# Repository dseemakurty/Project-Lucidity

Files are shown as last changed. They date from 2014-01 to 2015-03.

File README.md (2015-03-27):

Welcome to Project Lucidity

At its core, Project Lucidity is a sleep mask that helps you attain the elusive lucid dream. But this project is more than that. Its about taking the art of controlling your dreams and bringing it from a shaky phenomenon to a more understood science. To do so, Project Lucidity was designed as a fully featured, hobbyist and developer friendly, lucid dreaming mask that goes above and beyond. 

For more information about the project, check out the main website at: http://dseemakurty.wix.com/project-lucidity

All the code, schematics, and eagle files have been uploaded into this github. Feel free to utilize this information for your personal designs but please check the license file for any concerns about the contents use.

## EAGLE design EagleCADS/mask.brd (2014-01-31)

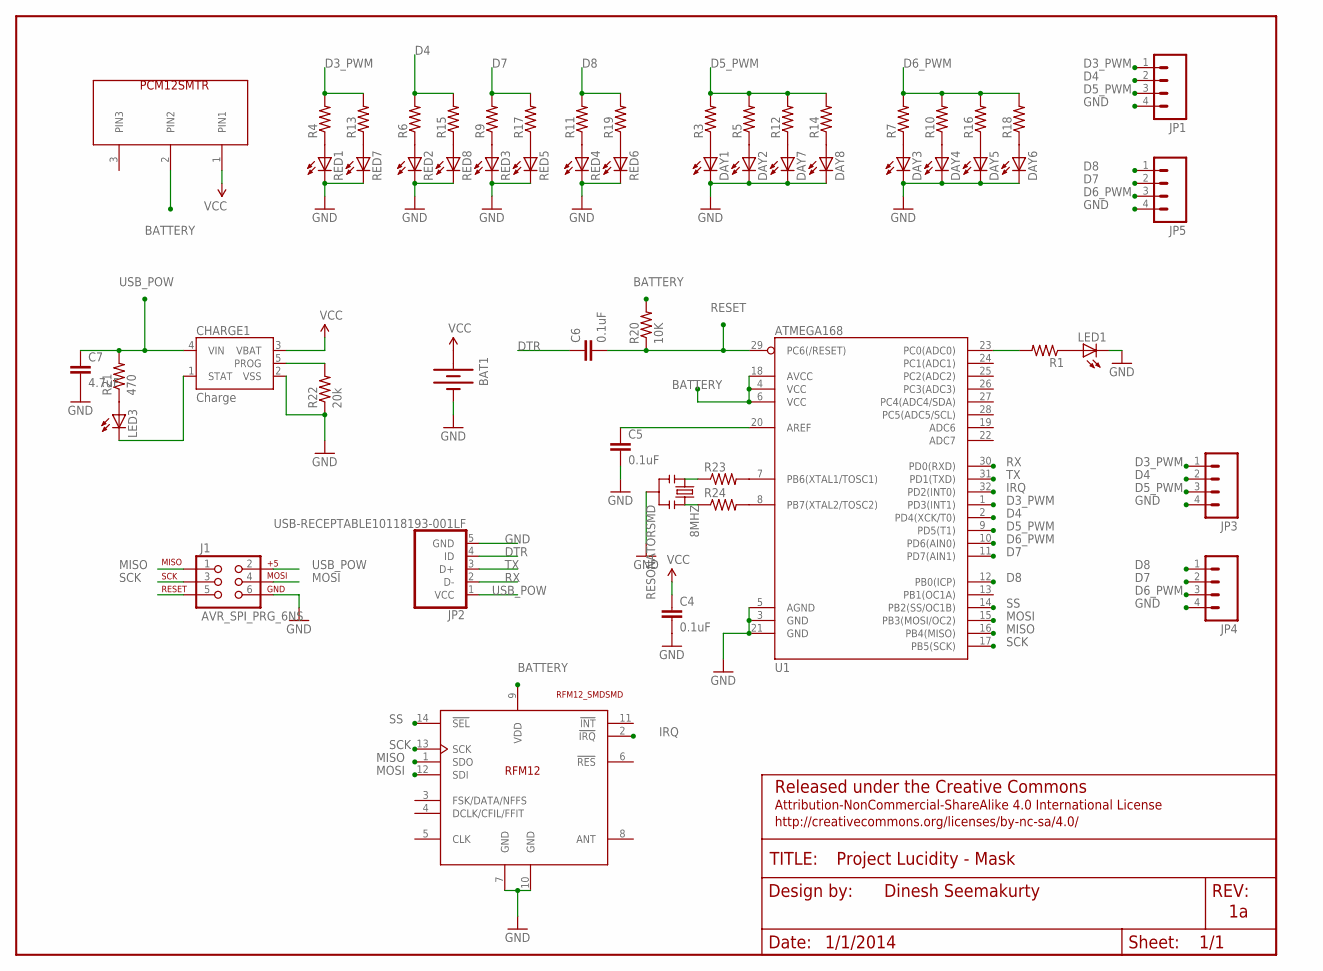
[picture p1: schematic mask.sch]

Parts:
8MHZ: RESONATORSMD; RESONATOR-SMD
BAT1: BATTERY245MM; BATTCON_245MM
C4, C5, C6: 0.1uF; 0805
C7: 4.7uF; 0805
CHARGE1: Charge; SOT23-5
DAY1, DAY2, DAY3, DAY4, DAY5, DAY6, DAY7, DAY8: LEDP-LCC-2; P-LCC-2
FRAME1: FRAME-LETTER; CREATIVE_COMMONS
J1: AVR_SPI_PRG_6NS; 2X3-NS
JP1, JP3, JP4, JP5: M04PTH; 1X04
JP2: USB-RECEPTABLE10118193-001LF; FCI-10118193-0001LF
LED1, LED3: LED0603; LED-0603
R1, R3, R4, R5, R6, R7, R9, R10, R11, R12, R13, R14, R15, R16, R17, R18, R19: RESISTOR0805-RES; 0805
R20: 10K; 0805
R21: 470; 0805
R22: 20k; 0805
R23, R24: RESISTOR0402-RES; 0402-RES
RED1, RED2, RED3, RED4, RED5, RED6, RED7, RED8: LEDCHIPLED_1206; CHIPLED_1206
U1: ATMEGA168; TQFP32-08
U$2: PCM12SMTR
U$3: RFM12_SMDSMD; RFM12

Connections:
BATTERY: R20.2, U1.4 (VCC), U1.6 (VCC), U1.18 (AVCC), U$2.2 (PIN2), U$3.9 (VDD)
D3_PWM: JP1.1, JP3.1, R4.2, R13.2, U1.1 (PD3(INT1))
D4: JP1.2, JP3.2, R6.2, R15.2, U1.2 (PD4(XCK/T0))
D5_PWM: JP1.3, JP3.3, R3.2, R5.2, R12.2, R14.2, U1.9 (PD5(T1))
D6_PWM: JP4.3, JP5.3, R7.2, R10.2, R16.2, R18.2, U1.10 (PD6(AIN0))
D7: JP4.2, JP5.2, R9.2, R17.2, U1.11 (PD7(AIN1))
D8: JP4.1, JP5.1, R11.2, R19.2, U1.12 (PB0(ICP))
DTR: C6.1, JP2.4 (ID)
GND: 8MHZ.2, BAT1.2 (-), C4.2, C5.2, C7.2, CHARGE1.2 (VSS), DAY1.P$2 (C), DAY2.P$2 (C), DAY3.P$2 (C), DAY4.P$2 (C), DAY5.P$2 (C), DAY6.P$2 (C), DAY7.P$2 (C), DAY8.P$2 (C), J1.6, JP1.4, JP2.5 (GND), JP3.4, JP4.4, JP5.4, LED1.C, R22.1, RED1.C, RED2.C, RED3.C, RED4.C, RED5.C, RED6.C, RED7.C, RED8.C, U1.3 (GND), U1.5 (AGND), U1.21 (GND), U$3.7 (GND), U$3.10 (GND)
IRQ: U1.32 (PD2(INT0)), U$3.2 (!IRQ)
MISO: J1.1, U1.16 (PB4(MISO)), U$3.1 (SDO)
MOSI: J1.4, U1.15 (PB3(MOSI/OC2)), U$3.12 (SDI)
unnamed: C5.1, U1.20 (AREF)
unnamed: LED1.A, R1.1
unnamed: R1.2, U1.23 (PC0(ADC0))
unnamed: DAY3.P$1 (A), R7.1
unnamed: DAY4.P$1 (A), R10.1
unnamed: DAY1.P$1 (A), R3.1
unnamed: R4.1, RED1.A
unnamed: R6.1, RED2.A
unnamed: DAY2.P$1 (A), R5.1
unnamed: LED3.A, R21.1
unnamed: R9.1, RED3.A
unnamed: R11.1, RED4.A
unnamed: CHARGE1.1 (STAT), LED3.C
unnamed: CHARGE1.5 (PROG), R22.2
unnamed: 8MHZ.1, R23.1
unnamed: 8MHZ.3, R24.1
unnamed: R13.1, RED7.A
unnamed: R15.1, RED8.A
unnamed: R23.2, U1.7 (PB6(XTAL1/TOSC1))
unnamed: R17.1, RED5.A
unnamed: R19.1, RED6.A
unnamed: DAY5.P$1 (A), R16.1
unnamed: DAY6.P$1 (A), R18.1
unnamed: DAY7.P$1 (A), R12.1
unnamed: DAY8.P$1 (A), R14.1
unnamed: R24.2, U1.8 (PB7(XTAL2/TOSC2))
RESET: C6.2, J1.5, R20.1, U1.29 (PC6(/RESET))
RX: JP2.2 (D-), U1.30 (PD0(RXD))
SCK: J1.3, U1.17 (PB5(SCK)), U$3.13 (SCK)
SS: U1.14 (PB2(SS/OC1B)), U$3.14 (!SEL)
TX: JP2.3 (D+), U1.31 (PD1(TXD))
USB_POW: C7.1, CHARGE1.4 (VIN), J1.2, JP2.1 (VCC), R21.2
VCC: BAT1.1 (+), C4.1, CHARGE1.3 (VBAT), U$2.1 (PIN1)

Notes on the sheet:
Released under the Creative Commons
Attribution-NonCommercial-ShareAlike 4.0 International License
http://creativecommons.org/licenses/by-nc-sa/4.0/
Project Lucidity - Mask
Dinesh Seemakurty
1/1/2014

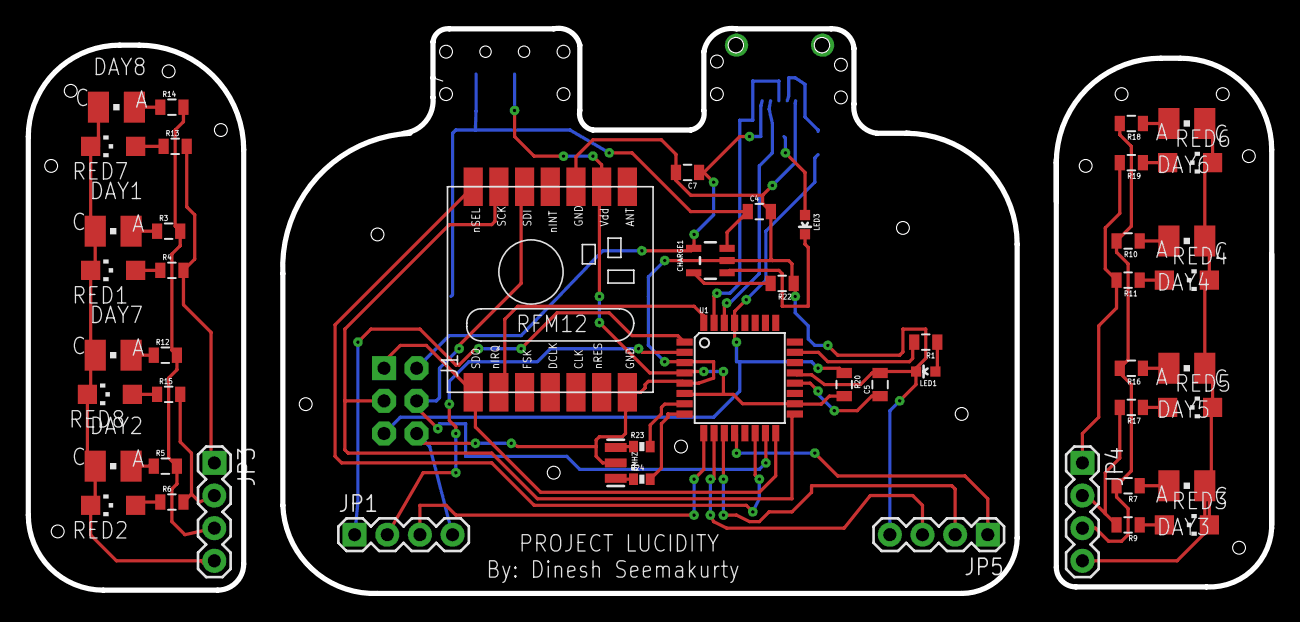
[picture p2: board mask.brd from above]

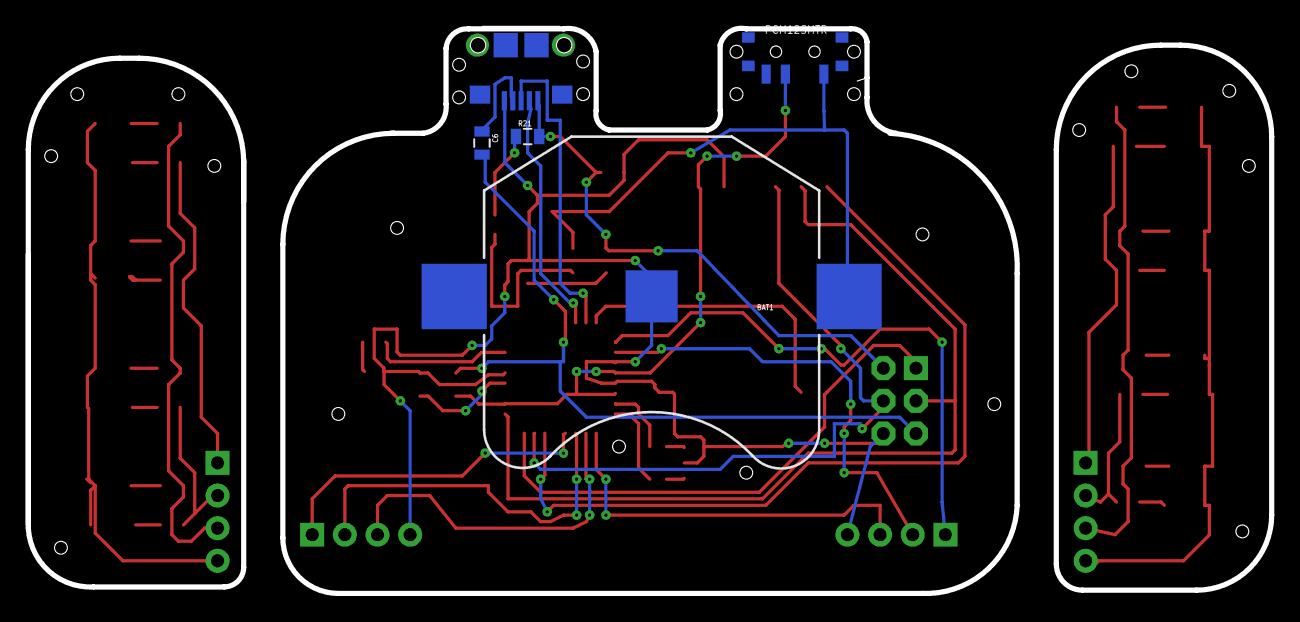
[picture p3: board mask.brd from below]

Board: 2 copper layers, 96.8 x 44.0 mm, 57 parts (5 on the bottom side), 45 nets.

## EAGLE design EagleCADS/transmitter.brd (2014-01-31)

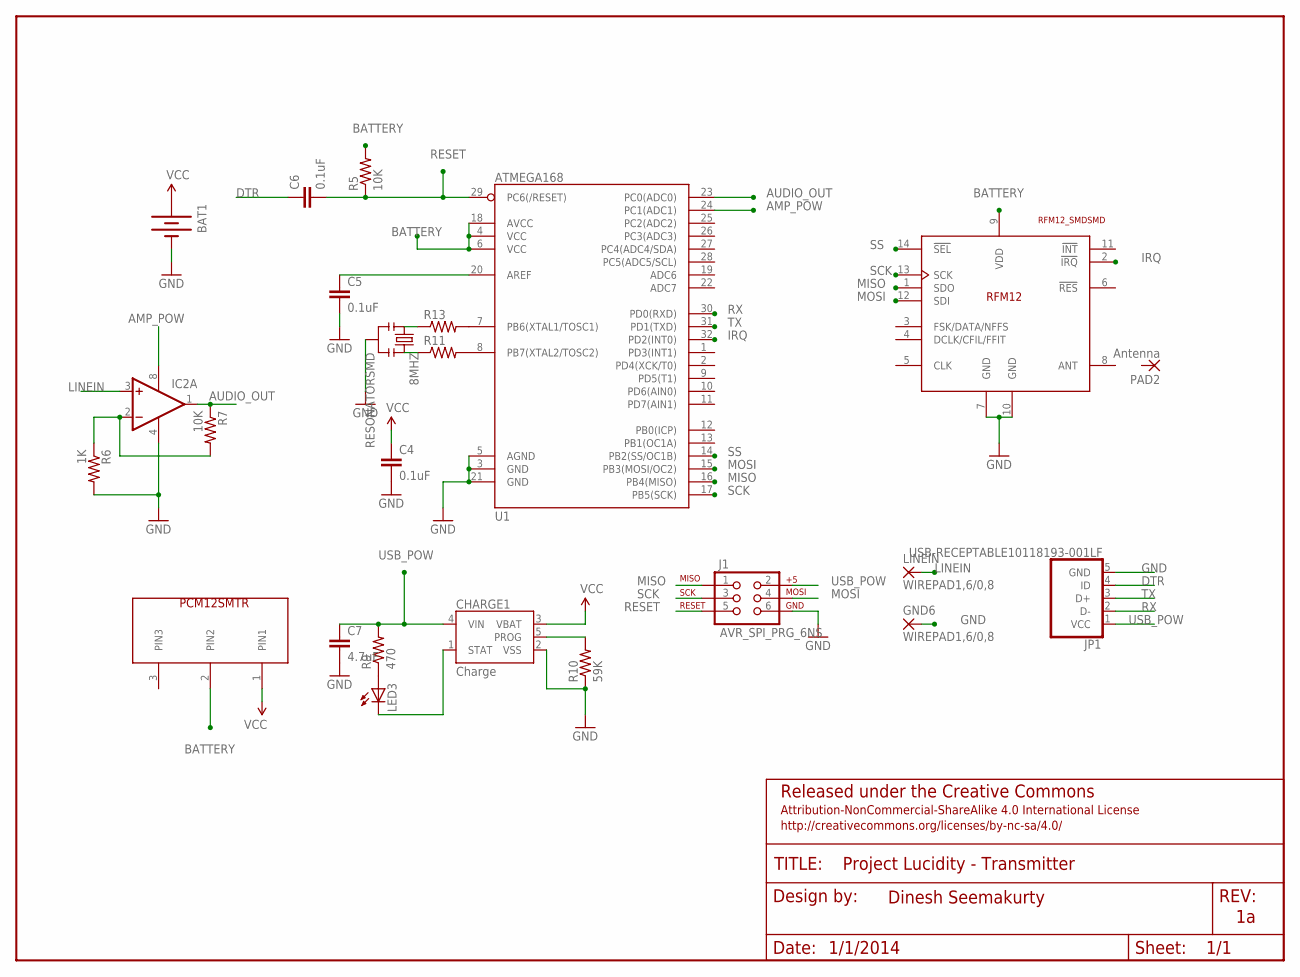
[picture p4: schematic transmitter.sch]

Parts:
8MHZ: RESONATORSMD; RESONATOR-SMD
BAT1: BATTERY20MM_4LEGS; BATTCON_20MM_4LEGS
C4, C5, C6: 0.1uF; 0805
C7: 4.7uF; 0805
CHARGE1: Charge; SOT23-5
FRAME1: FRAME-LETTER; CREATIVE_COMMONS
GND6: WIREPAD1,6/0,8; 1,6/0,8
IC2: LM358D; SO08
J1: AVR_SPI_PRG_6NS; 2X3-NS
JP1: USB-RECEPTABLE10118193-001LF; FCI-10118193-0001LF
LED3: LED0603; LED-0603
LINEIN: WIREPAD1,6/0,8; 1,6/0,8
PAD2: Antenna; SMD1,27-2,54
R5, R7: 10K; 0805
R6: 1K; 0805
R9: 470; 0805
R10: 59K; 0805
R11, R13: RESISTOR0402-RES; 0402-RES
U1: ATMEGA168; TQFP32-08
U$2: PCM12SMTR
U$3: RFM12_SMDSMD; RFM12

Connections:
AMP_POW: IC2.8 (V+), U1.24 (PC1(ADC1))
AUDIO_OUT: IC2.1 (OUT), R7.1, U1.23 (PC0(ADC0))
BATTERY: R5.2, U1.4 (VCC), U1.6 (VCC), U1.18 (AVCC), U$2.2 (PIN2), U$3.9 (VDD)
DTR: C6.1, JP1.4 (ID)
GND: 8MHZ.2, BAT1.GND (-), C4.2, C5.2, C7.2, CHARGE1.2 (VSS), GND6.1, IC2.4 (V-), J1.6, JP1.5 (GND), R6.2, R10.1, U1.3 (GND), U1.5 (AGND), U1.21 (GND), U$3.7 (GND), U$3.10 (GND)
IRQ: U1.32 (PD2(INT0)), U$3.2 (!IRQ)
LINEIN: IC2.3 (+IN), LINEIN.1
MISO: J1.1, U1.16 (PB4(MISO)), U$3.1 (SDO)
MOSI: J1.4, U1.15 (PB3(MOSI/OC2)), U$3.12 (SDI)
unnamed: R13.2, U1.7 (PB6(XTAL1/TOSC1))
unnamed: C5.1, U1.20 (AREF)
unnamed: R11.2, U1.8 (PB7(XTAL2/TOSC2))
unnamed: LED3.A, R9.1
unnamed: IC2.2 (-IN), R6.1, R7.2
unnamed: CHARGE1.1 (STAT), LED3.C
unnamed: CHARGE1.5 (PROG), R10.2
unnamed: 8MHZ.1, R13.1
unnamed: 8MHZ.3, R11.1
RESET: C6.2, J1.5, R5.1, U1.29 (PC6(/RESET))
RX: JP1.2 (D-), U1.30 (PD0(RXD))
SCK: J1.3, U1.17 (PB5(SCK)), U$3.13 (SCK)
SS: U1.14 (PB2(SS/OC1B)), U$3.14 (!SEL)
TX: JP1.3 (D+), U1.31 (PD1(TXD))
USB_POW: C7.1, CHARGE1.4 (VIN), J1.2, JP1.1 (VCC), R9.2
VCC: BAT1.POW1 (+), BAT1.POW2 (+), BAT1.POW3 (+), BAT1.POW4 (+), C4.1, CHARGE1.3 (VBAT), U$2.1 (PIN1)

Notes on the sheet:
Released under the Creative Commons
Attribution-NonCommercial-ShareAlike 4.0 International License
http://creativecommons.org/licenses/by-nc-sa/4.0/
Project Lucidity - Transmitter
Dinesh Seemakurty
1/1/2014

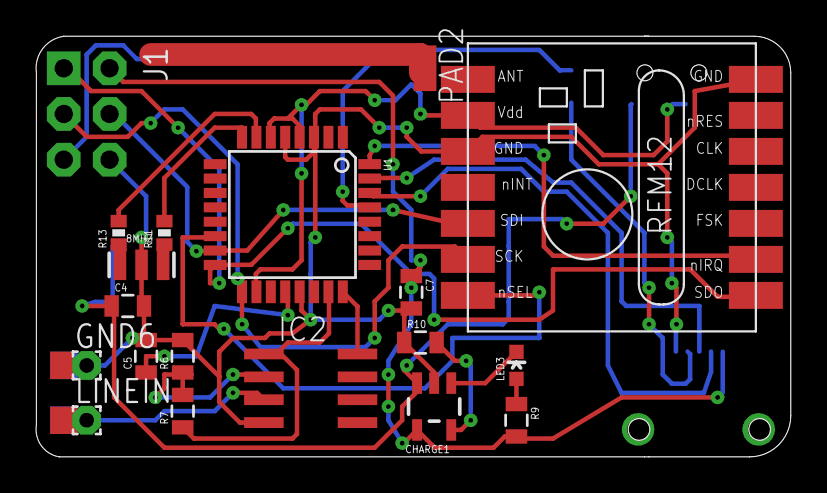
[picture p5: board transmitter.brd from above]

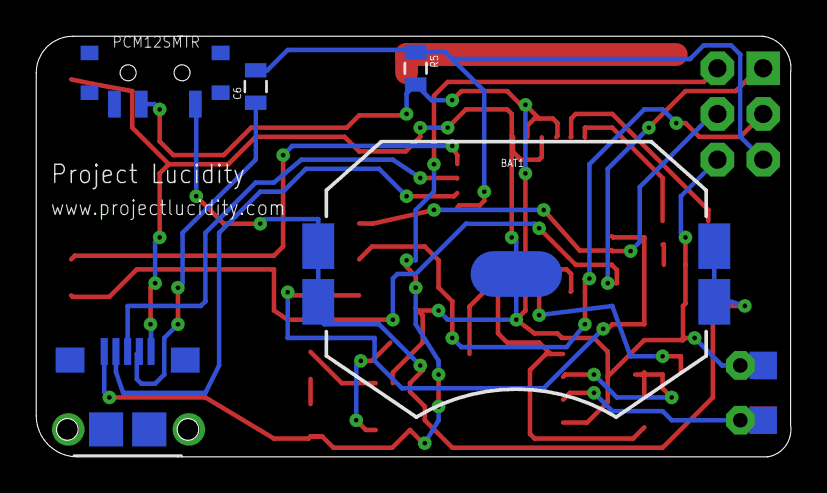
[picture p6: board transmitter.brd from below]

Board: 2 copper layers, 41.9 x 23.4 mm, 25 parts (5 on the bottom side), 25 nets.

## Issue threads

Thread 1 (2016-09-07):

BOM needed

autrion, 2016-09-07:
Hi, thanks for this great work! In my opinion the best mask out there as you could also use it e.g. as "alarm" which is not supported by other devices.

One thing: I could use a BoM (Bill of materials) in order to build it myselve. Is it possible to etch the board by oneselve?

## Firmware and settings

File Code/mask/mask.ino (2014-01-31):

#include <SoftPWM.h>
#include <SPI.h>
#include <avr/interrupt.h>
#include <avr/power.h>
#include <avr/sleep.h>
#include <avr/io.h>
#include <avr/wdt.h>
#include <RFM12B.h>

//**********************************************************************************//

#define numRedLeds 4
#define ledPin1 3
#define ledPin2 4
#define ledPin3 7
#define ledPin4 8
#define statusLED A0
int LEDS[numRedLeds] = {
  ledPin1,ledPin2,ledPin3,ledPin4};
int startOn[numRedLeds]; // the time in ISR time units when the LEDs should activate

#define daylightPin1 5
#define daylightPin2 6
#define daylightMaxBrightness 255 // the maximum brightness the LEDs can reach
#define daylightIncreaseInterval 1 // how much the PWM should increase per refresh (out of 255)
#define daylightInterval 2 // (255*(600ms/1000ms))/60s = 2.55 minutes
int daylightRefreshIntervalT; //interval between refreshes in terms of ISR time units, function of the daylightInterval and settings assigned by user
int daylightBrightness; //brightness of the daylight simulation as a function of received setting
int daylightFadeLevel = 0; // the fade level of the daylight LEDs

// @16Mhz overflow of 155 = 10ms :::: @8Mhz overflow of 78 = 10ms
#define timerOverflow 78 // this overflow amount on the 16bit Timer1 will create 10ms overflows
#define interruptInterval 10 //one ISR time unit is this many milliseconds based on clock calculations

//fade speeds for the different patterns
#define flashAllFadeTime 200
#define sweepFadeTime 200
#define alternatingFadeTime 200
#define doubleFlashFadeTime 50
int sweepDelay; //delay between LED's on the sweep pattern
double patternBrightness; // will be modified by received settings
double patternSpeed; // will be modified by received settings

int fadeTime; // how long the fading process should take in ms
int fadeT; // fadeTime in ISR time units
double redBrightnessPercent; // will be modified by various settings, the actual brightness of the red LEDs
double redFadeTime; //the time sent to the SoftPWM library incorporating brightness level and actual fadeTime
#define patternRefillTime 30000 // how long a pattern will project after receiving the signal
#define previewPatternRefillTime 3000
int patternDisplayTime; // how long a pattern should be displayed, must be refilled with time after use
int patternT = 0; // patternDisplayTime in ISR time units

volatile long redT = 0; // ticks every timer overflow
volatile long daylightT = 0; // ticks only when runDaylight boolean is enabled

boolean runDaylight = false; //triggers Daylight Simulation
boolean flashAllP = false; //triggers all LEDs to flash pattern
boolean sweepRightP = false; // triggers sweep pattern (ONLY ENABLE RIGHT OR LEFT TO START SWEEP)
boolean sweepLeftP = false; // triggers sweep pattern (ONLY ENABLE RIGHT OR LEFT TO START SWEEP)
boolean alternatingFlashP = false; // triggers flashing of each eye's LEDs alternatingly
boolean doubleFlashP = false; // double flash then delayLong
int longCount = -1;
int delayLong;
boolean *patternPointer; // boolean to point to one of the above booleans (used in updateReds() method)
int resetT = -1; // when the pattern is finished one cycle in ISR time units

#define NODEID 1
#define NETWORKID 99
unsigned int msg; // the message that will be received from the tranceiver
RFM12B radio;
boolean keepListening = true; // 
long startListeningTime;
#define listenTimeout 200 //how long to listen before timeing out

// Watchdog timeout values
// 0=16ms, 1=32ms, 2=64ms, 3=128ms, 4=250ms, 5=500ms
// 6=1sec, 7=2sec, 8=4sec, 9=8sec
#define wdTime 9 // watchdog timeout value
#define tempwdTime 6
#define wdMultiple 3 // how many times to execute wdTime (gets larger sleep times)
#define tempwdMultiple 1 // how many times to execute wdTime (gets larger sleep times)
#define idleTimeout 4320 //multiply by wdTime(ms value) and wdMultiple to get the time of the timeout, will put mask into deep sleep without WDT
#define tempIdleTimeout 60 // preview timeout allows for quick polling (set for 1 minute)
long idleTimer = 0; // counter that is compared to the sleepTimeout
volatile boolean f_wdt = 0; // WDT int
byte adcsra;

void setup()
{
  SoftPWMBegin();
  Serial.begin(115200);
  pinMode(statusLED,OUTPUT);
  setupTimerInterrupt();
  radio.Initialize(NODEID,RF12_433MHZ,NETWORKID);
  Serial.println("Listening..");
}

// sets up all the calculations around properly fading the LEDs
void setupSoftPWM(int fadetime, double brightness)
{
  fadeTime = fadetime;
  fadeT = fadeTime/interruptInterval;
  redBrightnessPercent = brightness;
  redFadeTime = fadeTime*(100/redBrightnessPercent); // recalculates the time for the SoftPWM library since library times things differently
  sweepDelay = fadeT/2;
  delayLong = fadeT*10;
  SoftPWMSet(ledPin1, 0);
  SoftPWMSetFadeTime(ledPin1, redFadeTime, redFadeTime);
  SoftPWMSet(ledPin2, 0);
  SoftPWMSetFadeTime(ledPin2, redFadeTime, redFadeTime);
  SoftPWMSet(ledPin3, 0);
  SoftPWMSetFadeTime(ledPin3, redFadeTime, redFadeTime);
  SoftPWMSet(ledPin4, 0);
  SoftPWMSetFadeTime(ledPin4, redFadeTime, redFadeTime);
}

// sets up timer 1 with 10ms overflow
void setupTimerInterrupt()
{
  cli();          // disable global interrupts
  TCCR1A = 0;     // set entire TCCR1A register to 0
  TCCR1B = 0;     // same for TCCR1B
  OCR1A = timerOverflow; // set to overflow ever 10ms
  TCCR1B |= (1 << WGM12); // turn on CTC mode:
  TCCR1B |= (1 << CS10);  // Set CS10 and CS12 bits for 1024 prescaler:
  TCCR1B |= (1 << CS12);
  TIMSK1 |= (1 << OCIE1A); // enable timer compare interrupt:
  sei();          // enable global interrupts
}

void analyzeMessage(unsigned int msg)
{

  double brightSetting = msg%10;  // the ones digit of the int received is the brightness setting
  msg = msg/10;                   // remove ones digit
  double speedSetting = msg%10;   // the previously tens digit is speed setting
  msg = msg/10;                   // remove ones digit
  int patternSetting = msg;       // the rest is the pattern indicator

  if (patternSetting == 1){
    daylightBrightness = daylightMaxBrightness * (brightSetting+1)/10;
    daylightRefreshIntervalT = daylightInterval * (speedSetting+1);
    runDaylight =true;
  }
  if (patternSetting == 2){
    patternBrightness = (brightSetting+1)*10;
    patternSpeed = flashAllFadeTime*10/(speedSetting+1);
    if (idleTimer<=tempIdleTimeout)
      setPattern(&flashAllP,previewPatternRefillTime,patternBrightness,patternSpeed);
    else setPattern(&flashAllP,patternRefillTime,patternBrightness,patternSpeed);
  }
  else if (patternSetting == 3){
    patternBrightness = (brightSetting+1)*10;
    patternSpeed = sweepFadeTime*10/(speedSetting+1);
    if (idleTimer<=tempIdleTimeout)
      setPattern(&sweepRightP,previewPatternRefillTime,patternBrightness,patternSpeed);
    else setPattern(&sweepRightP,patternRefillTime,patternBrightness,patternSpeed);
  }
  else if (patternSetting == 4){
    patternBrightness = (brightSetting+1)*10;
    patternSpeed = alternatingFadeTime*10/(speedSetting+1);
    if (idleTimer<=tempIdleTimeout)
      setPattern(&alternatingFlashP,previewPatternRefillTime,patternBrightness,patternSpeed);
    else setPattern(&alternatingFlashP,patternRefillTime,patternBrightness,patternSpeed);
  }
  else if (patternSetting == 5){
    patternBrightness = (brightSetting+1)*10;
    patternSpeed = doubleFlashFadeTime*10/(speedSetting+1);
    if (idleTimer<=tempIdleTimeout)
      setPattern(&doubleFlashP,previewPatternRefillTime,patternBrightness,patternSpeed);
    else setPattern(&doubleFlashP,patternRefillTime,patternBrightness,patternSpeed);
  }
}

void listenMessage()
{
  startListeningTime = millis();
  keepListening = true;
  while(millis()-startListeningTime<200 && keepListening) // listen for data for set time
  {
    if (radio.ReceiveComplete())
    {
      keepListening = false;
      if (radio.CRCPass())
      {
        char buffer[16]; // create character array
        for (byte i = 0; i < radio.GetDataLen(); i++)
          buffer[i] = (char)radio.Data[i];  // populate character array with data array
        int msg = atoi(buffer); // convert char array into an integer
        Serial.println(msg);
        radio.SendACK(); // send acknowledgement packet
        analyzeMessage(msg);
      }
    }
  }
}

void setPattern(boolean *patternpointer, int time, int brightness, int fadeSpeed)
{
  patternDisplayTime = time; // sets how long the pattern will be shown
  patternT = patternDisplayTime/interruptInterval; // recalculates time in ISR time units
  setupSoftPWM(fadeSpeed,brightness); // adjusts the SoftPWM settings
  *patternpointer = true; // activates the boolean that is sent to the method
}

void updateDaylight()
{
  if (daylightFadeLevel<=daylightBrightness){
    daylightFadeLevel+=daylightIncreaseInterval; // increase the PWM of the daylight LEDs
    analogWrite(daylightPin1, daylightFadeLevel);
    analogWrite(daylightPin2, daylightFadeLevel);
  }
  else{
    analogWrite(daylightPin1, 0); // turn off daylight LEDs
    analogWrite(daylightPin2, 0);
    daylightFadeLevel = 0;
    runDaylight = false; // technically unnecessary
    powerDown(); // after a daylight simulation, put the mask into deep sleep without WDT, requires manual reset
  }
}

void updateReds()
{
  for(int i = 0; i < numRedLeds;i++){
    if (redT == startOn[i]){ // iterates through all the LEDs and updates them based on the ISR time units
      SoftPWMSetPercent(LEDS[i],redBrightnessPercent);
    }
    else if (redT == startOn[i]+fadeT){ // turn off LEDs if they have reached peak brightness
      SoftPWMSetPercent(LEDS[i],0);
    }
  }
  if (redT==resetT){
    *patternPointer = true; // the value of the boolean that patternBoolean is addressed to is equal to True
    patternT-=resetT; // subracts the time for pattern to complete one cycle from the allotted display time
  }
}

void loop()
{

  if (f_wdt == 1){
    f_wdt=0;
    wdt_disable();
    
    radio.Wakeup();
    listenMessage();
    radio.Sleep();
  }
  else if (patternT<=0 && runDaylight == false){ // if freshly booted, poll at faster rate
    if (idleTimer<=tempIdleTimeout){
      setup_watchdog(tempwdTime);
      idleTimer++;
      timedSleep(tempwdMultiple);
    }
    else if (idleTimer<=idleTimeout){ //if activity timeout hasnt occured, enable watchdog and sleep
      setup_watchdog(wdTime);
      idleTimer++; // iterate idle timer
      timedSleep(wdMultiple); // put MCU to sleep
    }
    else{ // if timeout has occured, go into sleep without interrupts. can only be woken by reset button
      powerDown();
    }
  }

  // check all the pattern booleans to display pattern if one is valid
  if (flashAllP){
    redT=0;
    startOn[0] = redT+10;
    startOn[1] = redT+10;
    startOn[2] = redT+10;
    startOn[3] = redT+10;
    resetT = redT+10+fadeT*2; // the last possible redT that this pattern requires
    patternPointer = &flashAllP; //patternBoolean is the address of flashAll
    flashAllP = false;
    redT=0;
  }

  else if (sweepRightP){
    redT=0;
    startOn[0] = redT;
    startOn[1] = redT+sweepDelay;
    startOn[2] = redT+sweepDelay*2;
    startOn[3] = redT+sweepDelay*3;
    resetT = redT+sweepDelay*3+fadeT*2; // the last possible redT that this pattern requires for one cycle
    patternPointer = &sweepLeftP; //patternBoolean is the address of left sweep so sweep continues
    sweepRightP = false;
    redT=0;
  }

  else if (sweepLeftP){
    redT=0;
    startOn[3] = redT;
    startOn[2] = redT+sweepDelay;
    startOn[1] = redT+sweepDelay*2;
    startOn[0] = redT+sweepDelay*3;
    resetT = redT+sweepDelay*3+fadeT*2; // the last possible redT that this pattern requires for one cycle
    patternPointer = &sweepRightP; //patternBoolean is the address of right sweep so sweep continues
    sweepLeftP = false;
    redT=0;
  }

  else if (alternatingFlashP){
    redT=0;
    startOn[0] = redT;
    startOn[1] = redT;
    startOn[2] = redT+fadeT*2;
    startOn[3] = redT+fadeT*2;
    resetT = redT+fadeT*4; // the last possible redT that this pattern requires for one cycle
    patternPointer = &alternatingFlashP; //patternBoolean is the address of alternating flash
    alternatingFlashP = false;
    redT=0;
  }

  else if (doubleFlashP){
    if (longCount == 1){ // after two blinks, take long pause
      longCount = 0;
      redT=0;
      startOn[0] = redT+delayLong+10; // delayLong is a multiple of the fade
      startOn[1] = redT+delayLong+10;
      startOn[2] = redT+delayLong+10;
      startOn[3] = redT+delayLong+10;
      resetT = redT+delayLong+fadeT*4; // the last possible redT that this pattern requires for one cycle
    }
    else { 
      longCount++;
      redT=0;
      startOn[0] = redT+10;
      startOn[1] = redT+10;
      startOn[2] = redT+10;
      startOn[3] = redT+10;
      resetT = redT+fadeT*4; // the last possible redT that this pattern requires for one cycle
    }
    patternPointer = &doubleFlashP; //patternBoolean is the address of double flash
    doubleFlashP = false;
    redT=0;
  }
}

// Main timer that allows for smooth updating of patterns, interrupts ever 10ms
ISR(TIMER1_COMPA_vect)
{
  if (runDaylight){
    daylightT++;
    if (daylightT >= daylightRefreshIntervalT)
    {
      updateDaylight();
      daylightT = 0;
    }
  }
  if (patternT>0){
    updateReds();
    redT++;
  }
}


//*********************************************************************************************//
//*********************************************************************************************//

// allows for longer sleep times which are multiples of wdTime
void timedSleep(int waitTime)
{
  int waitCounter = 0;
  while (waitCounter != waitTime) 
  {
    enterSleep();
    waitCounter++;
  }
}

// puts the mC to power down sleep and has no interrupt or watchdog, can only be awoken by reset
void powerDown()
{
  digitalWrite(statusLED,LOW);
  enterSleep();
}


//*********************************************************************************************//
//*********************************************************************************************//

//sets up the watchdog to the correct sleep time
void setup_watchdog(int ii) 
{  
  // The prescale value is held in bits 5,2,1,0
  // This block moves ii itno these bits
  byte bb;
  if (ii > 9 ) ii=9;
  bb=ii & 7;
  if (ii > 7) bb|= (1<<5);
  bb|= (1<<WDCE);

  // Reset the watchdog reset flag
  MCUSR &= ~(1<<WDRF);
  // Start timed sequence
  WDTCSR |= (1<<WDCE) | (1<<WDE);
  // Set new watchdog timeout value
  WDTCSR = bb;
  // Enable interrupts instead of reset
  WDTCSR |= _BV(WDIE);
}


void enterSleep(void)
{
  set_sleep_mode(SLEEP_MODE_PWR_DOWN);  // Choose our preferred sleep mode:
  sleep_enable();    // Set sleep enable (SE) bit::
  adcsra = ADCSRA; // save ADCSRA settings
  ADCSRA = 0; // disable ADC
  digitalWrite(statusLED,LOW);   // turn LED off to indicate sleep
  //enables software disabled BOD - means that BOD is disabled during sleep and is reenabled during wake up
  // cli(); // disable interrupts to softBOD disable
  MCUCR |= bit(BODSE) | bit(BODS); // timed sequence
  MCUCR = (MCUCR & ~bit(BODSE)) | bit(BODS);
  // sei(); // reenable interrupts to ensure wakeup from sleep
  sleep_cpu(); // puts the mcu to sleep
  // **SLEEP** //
  sleep_disable();   // Upon waking up, sketch continues from this point.
  ADCSRA = adcsra; // renable ADC
  digitalWrite(statusLED,HIGH);   // turn LED on to indicate awake
}

// Watchdog Interrupt Service is executed and volatile switch is turned on
ISR(WDT_vect){
  f_wdt = 1;
}

//*********************************************************************************************//
//*********************************************************************************************//

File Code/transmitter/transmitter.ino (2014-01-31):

#include <SPI.h>
#include <RFM12B.h>
#include <avr/interrupt.h>
#include <avr/power.h>
#include <avr/sleep.h>
#include <avr/io.h>
#include <avr/wdt.h>

//**********************************************************************************//

#define audioInPin A0 //input of audio signal from OpAmp
#define ampPin A1 // power pin of opAmp
#define silenceBarrier 200 //value under which silence is counted

//**if you change any of the bit values, the signal noises must be REDONE! ** WILL CAUSE ERRORS IF YOU DONT
#define oneBit 1000 // the micros time that signifies a 1
#define zeroBit 2000 //the micros time that signifies a 0
#define nullBit 3000 // the micros time that signifies a null, generally the end of a message
#define bitAccuracy 400 // the +/- of each of the microsecond times of the bits
long normalizer = 0; // gets rid of noise in audio data

#define alarmMsg 100 // predetermined message to receive from audio signal to denote alarm procedure
#define analyzeSamples 15 // how many messages to check at once per anaylzeData() call
#define continuityCheck 5 // how many messages must be same and continuous in order to transmit msg

//#define normalizerSamples 10000 // how many samples to take for noise reduction


#define NODEID 2
#define NETWORKID 99
#define GATEWAYID  1  //the node ID we're sending to
#define ACK_TIME 50  // # of ms to wait for an ack
unsigned int msg; // the message that will be received from the tranceiver
RFM12B radio;

boolean previewMode = true;
#define previewTransmitTimeout 2000 // how long to tansmit if acknowledgement is not received during preview mode
#define transmitTimeout 30000 // how long transmit should last if acknowledgment is not received
int transmitterTimeout = transmitTimeout;
// Watchdog timeout values
// 0=16ms, 1=32ms, 2=64ms, 3=128ms, 4=250ms, 5=500ms
// 6=1sec, 7=2sec, 8=4sec, 9=8sec
#define wdTime 9 // watchdog timeout value
#define tempwdTime 5
#define wdMultiple 2 // how many times to execute wdTime (gets larger sleep times)
#define tempwdMultiple 1 // how many times to execute wdTime (gets larger sleep times)
#define idleTimeout 2440 //multiply by wdTime(ms value) and wdMultiple to get the time of the timeout, will put mask into deep sleep without WDT
#define tempIdleTimeout 120 // preview timeout allows for quick polling (set for 1 minute)
long idleTimer = 0; // counts how long the transmitter was idle
volatile boolean f_wdt = 0; // keeps track of WDT wakeups
byte adcsra;

void setup(){
   
  analogReference(INTERNAL); // allows for easier readings from audio
  Serial.begin(115200);
  Serial.println("hey");
  radio.Initialize(NODEID,RF12_433MHZ,NETWORKID);
  
  pinMode(ampPin, OUTPUT);
  pinMode(audioInPin,INPUT);
  radio.Sleep();
   
} 

void loop(){
  if (f_wdt == 1){
    f_wdt=0;
    wdt_disable();
    digitalWrite(ampPin,HIGH);
    analyzeBits(500); // check to see if any audio signal recieved, timeout at 200ms
    digitalWrite(ampPin,LOW);
  }
  else{
    if (idleTimer<=tempIdleTimeout){
      setup_watchdog(tempwdTime);
      idleTimer++;
      timedSleep(tempwdMultiple);
    }
    else if (idleTimer<=idleTimeout){ //if activity timeout hasnt occured, enable watchdog and sleep
      previewMode = false;
      transmitterTimeout = transmitTimeout;
      setup_watchdog(wdTime);
      idleTimer++;
      timedSleep(wdMultiple);
    }
    else{ // if timeout has occured, go into sleep without interrupts. can only be woken by reset button
      powerDown();
    }
  }
}

// maximum value that can be transmitted is 16bits = max value of 65535
void transmitData(char msg[])
{
  long startTime = millis();
  radio.Wakeup();
  Serial.println("transmitting");
  while (millis()-startTime<transmitterTimeout && !waitForAck())
  {
    radio.Send(GATEWAYID,msg,sizeof(msg)+1,true);
  } // try until acknowledgement is received or timeout at 2s
   Serial.println("finished");
   delay(100);
  radio.Sleep();
}

static bool waitForAck() {
  long now = millis();
  while (millis() - now <= ACK_TIME)
    if (radio.ACKReceived(GATEWAYID))
      return true;
  return false;
}

void analyzeBits(int timeOut){
  long startTime = millis();
  int continous = 0;
  int breakCount = 0;
  unsigned int msg = 0;
  while (msg==0 && millis()-startTime<timeOut){ // ensures that msg is a valid reading and has timeout
    msg = getBits();
  }
  long check = 0; 

  while(millis()-startTime<timeOut) // checks messages for continouity, has timeout
  {
    while(check==0 && millis()-startTime<timeOut) // ensures that check if a valid reading
      check = getBits();
    if (check == msg){ // tallies how many continous consistant readings there are
      continous++;
      startTime = millis(); // if valid readings are obtained, extend the timeout
    }
    else{
      msg = check;
      continous = 0;
      startTime = millis(); // if valid readings are obtained, extend the timeout
    }
    if (continous >= continuityCheck){ // if there are enough consistent readings, it must be accurate
      
      String message = String(msg);
      char cstr[16];
      String(msg).toCharArray(cstr,16);
      Serial.println(cstr);
      Serial.println(sizeof(cstr));
      transmitData(cstr);
      
      return; 
    }
  }
  return;
}

// read the bits from the signals and create an integer out of them
long getBits(){
  unsigned int message = 0;
  boolean contRead = true;
  int z = readSignal();
  if (z==-1){ //ensure that reading doesnt begin during middle of message
    while (contRead){
      z = readSignal(); // read the bit
      if (abs(z-oneBit) < bitAccuracy){ // check if its a 1
        message = message << 1; // shift bits over 1
        message += 1<<0; // place 1 at last bit
      }
      else if (abs(z-zeroBit) < bitAccuracy){ // check if its a 0
        message = message << 1; //shift bits over 1
        message += 0<<0; //place 0 at last bit
      }
      else if (z == -1){
        contRead = false;
        if (message > 0){
          return(message); // if valid message, return it
        }
        else return(0);
      }
    }
  }
  return 0;
}


int readSignal(){
  int outputValue;
  int startTime;
  int totalTime;
  startTime = 0;
  totalTime = 0;                 
  outputValue = analogRead(audioInPin); // read the value of the audio pin
  if (outputValue < silenceBarrier){ 
    startTime = micros(); // once the audio signal becomes close to silent, start timer
    while (outputValue < silenceBarrier){ // continue timer as long as audio signal is silent
      totalTime = micros();
      outputValue = analogRead(audioInPin); 
      if (totalTime-startTime > nullBit-bitAccuracy) // if signal is silent for too long, its a null pulse
        return -1;
    }
    totalTime = totalTime - startTime; // calculate total time and return it
  }  
  //Serial.println(totalTime);
  return(totalTime);
}
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

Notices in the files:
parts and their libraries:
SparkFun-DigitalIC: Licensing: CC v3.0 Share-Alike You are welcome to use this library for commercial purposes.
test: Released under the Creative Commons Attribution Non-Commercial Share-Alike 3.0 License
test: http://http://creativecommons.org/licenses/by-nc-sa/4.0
